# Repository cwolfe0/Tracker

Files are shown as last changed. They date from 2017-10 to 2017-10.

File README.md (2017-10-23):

# SHC HAB Tracker
This is the Eagle schematic and board file for the Space Hardware Club HAB tracker.
It is capable of recording GPS, rotation data, pressure and temperature and sending the information via APRS and recording it to an SD card.

The board uses a:
- GPS
- Magnetometer
- MCU
- 5V Regulator
- 3.3V Regulator
- 2 Surefire C123A Batteries in series (6V, 3000mAh)
- APRS-capable Radio
- 2 Logic Gates (for allowing 5V input to the radio from the MCU)
- Pressure Sensor
- Slider Switch
- PDI Interface

Top Image Top of Board
Bottom Image Bottom of Board
Board Image

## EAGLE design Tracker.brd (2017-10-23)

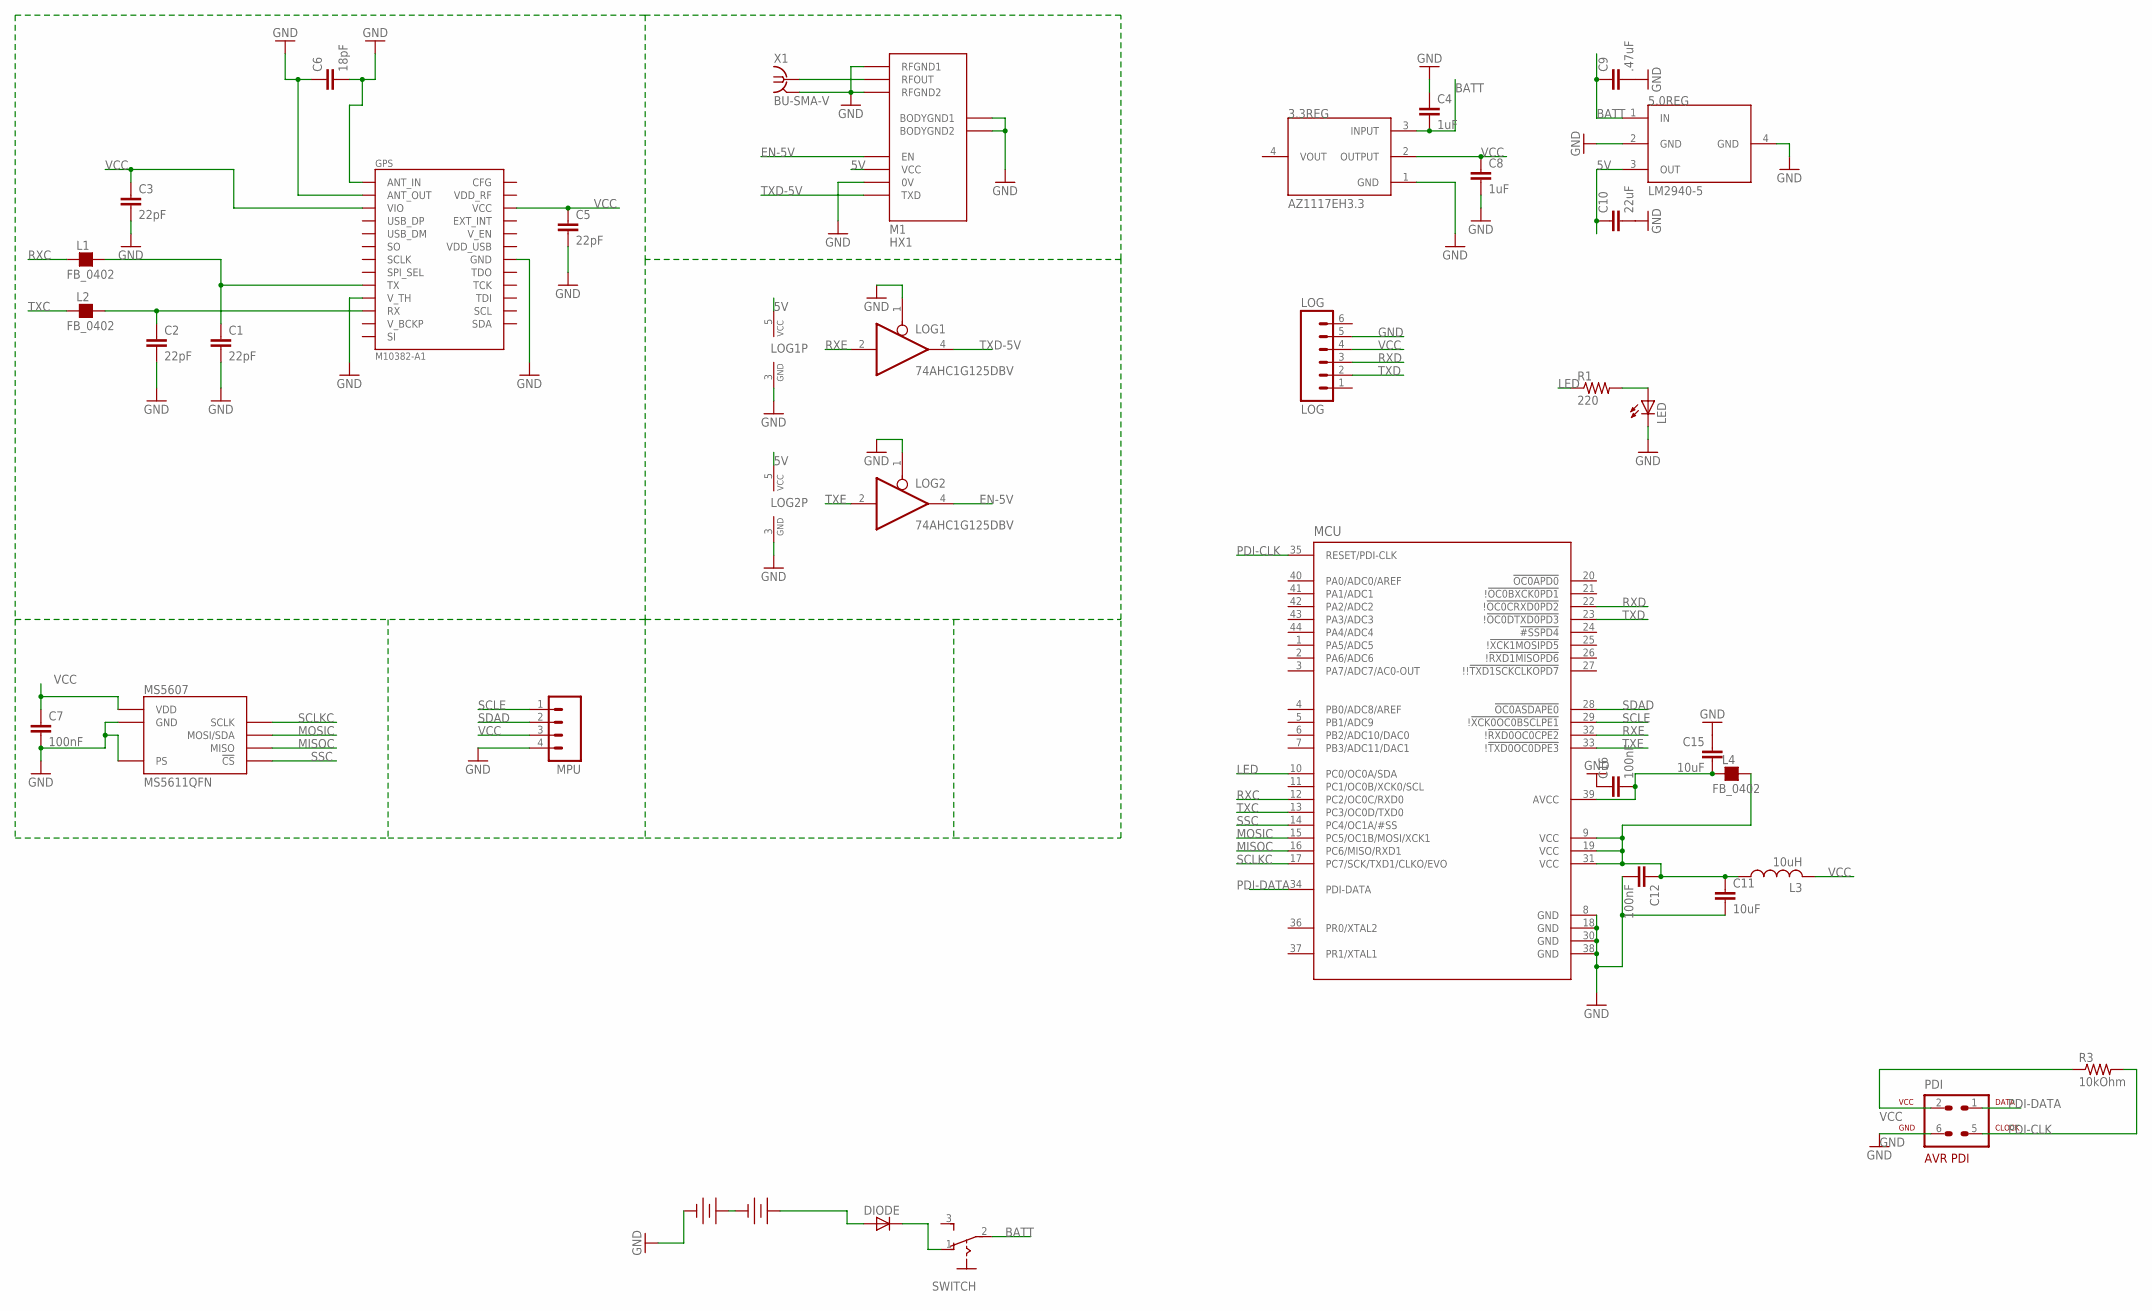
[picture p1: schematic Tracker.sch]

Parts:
3.3REG: AZ1117EH3.3; SOT-223
5.0REG: LM2940-5; SOT-223
BATT1, BATT2: 123_BATTERY_HOLDERCR-123-A; CR-123-A_HOLDER
C1, C2, C3, C5: 22pF; 0805
C4, C8: 1uF; 0603-CAP
C6: 18pF; 0805
C7, C12, C16: 100nF; 0805
C9: .47uF; 0603-CAP
C10: 22uF; 0603-CAP
C11, C15: 10uF; 0805
DIODE: LILYPAD-WEARABLES_LED1206; LILYPAD-WEARABLES_LED-1206
GPS: M10382-A1
L1, L2, L4: FB_0402; L0402
L3: 10uH; L2012C
LED: LEDCHIP-LED0603; CHIP-LED0603
LOG: LOG; SPARKFUN_1X06
LOG1, LOG2: 74AHC1G125DBV; SOT23-5
M1: HX1
MCU: AT-XMEGA-XXA4-AU; QFP80P1200X1200X120-44N
MPU: M04; 04P
MS5607: MS5611QFN; MS5611-01BA01
PDI: AVR-7_AVR-PDIVERT; AVR-7_AVR-ISP-6
R1: 220; R0603
R3: 10kOhm; 0805
SWITCH: M251
X1: BU-SMA-V

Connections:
5V: 5.0REG.3 (OUT), C10.1, LOG1.5 (VCC), LOG2.5 (VCC), M1.VCC
AVCC: C15.2, C16.2, L4.1, MCU.39 (AVCC)
BATT: 3.3REG.3 (INPUT), 5.0REG.1 (IN), C4.2, C9.1, SWITCH.2
EN-5V: LOG2.4 (O), M1.EN
GND: 3.3REG.1 (GND), 5.0REG.2 (GND), 5.0REG.4 (GND), BATT2.-, C1.2, C2.2, C3.2, C4.1, C5.2, C6.1, C6.2, C7.2, C8.2, C9.2, C10.2, C11.2, C12.2, C15.1, C16.1, GPS.1 (ANT_IN), GPS.2 (GND), GPS.3 (ANT_OUT), GPS.4 (GND), GPS.12 (V_TH), GPS.14 (GND), GPS.17 (GND), GPS.21 (GND), GPS.24 (GND), GPS.26 (GND), GPS.28 (GND), GPS.33 (GND), GPS.34 (GND), GPS.35 (GND), GPS.36 (GND), LED.C, LOG.5, LOG1.1 (OE), LOG1.3 (GND), LOG2.1 (OE), LOG2.3 (GND), M1.0V, M1.BODYGND1, M1.BODYGND2, M1.RFGND1, M1.RFGND2, MCU.8 (GND), MCU.18 (GND), MCU.30 (GND), MCU.38 (GND), MPU.4, MS5607.2 (PS), MS5607.3 (GND), PDI.6, X1.2 (GND), X1.3 (GND), X1.4 (GND), X1.5 (GND)
LED: MCU.10 (PC0/OC0A/SDA), R1.1
MISOC: MCU.16 (PC6/MISO/RXD1), MS5607.6 (MISO)
MOSIC: MCU.15 (PC5/OC1B/MOSI/XCK1), MS5607.7 (MOSI/SDA)
unnamed: C1.1, GPS.11 (TX), L1.2
unnamed: C2.1, GPS.13 (RX), L2.2
unnamed: BATT1.-, BATT2.+
unnamed: M1.RFOUT, X1.1
unnamed: BATT1.+, DIODE.A
unnamed: DIODE.C, SWITCH.1 (O)
unnamed: LED.A, R1.2
unnamed: C11.1, C12.1, L3.1, L4.2, MCU.9 (VCC), MCU.19 (VCC), MCU.31 (VCC)
PDI-CLK: MCU.35 (RESET/PDI-CLK), PDI.5, R3.2
PDI-DATA: MCU.34 (PDI-DATA), PDI.1
RXC: L1.1, MCU.12 (PC2/OC0C/RXD0)
RXD: LOG.3, MCU.22 (!!OC0CRXD0PD2)
RXE: LOG1.2 (I), MCU.32 (!!RXD0OC0CPE2)
SCLE: MCU.29 (!!XCK0OC0BSCLPE1), MPU.1
SCLKC: MCU.17 (PC7/SCK/TXD1/CLKO/EVO), MS5607.8 (SCLK)
SDAD: MCU.28 (!OC0ASDAPE0), MPU.2
SSC: MCU.14 (PC4/OC1A/#SS), MS5607.4 (!CS!), MS5607.5 (!CS!)
TXC: L2.1, MCU.13 (PC3/OC0D/TXD0)
TXD: LOG.2, MCU.23 (!!OC0DTXD0PD3)
TXD-5V: LOG1.4 (O), M1.TXD
TXE: LOG2.2 (I), MCU.33 (!!TXD0OC0DPE3)
VCC: 3.3REG.2 (OUTPUT), C3.1, C5.1, C7.1, C8.1, GPS.5 (VIO), GPS.27 (VCC), L3.2, LOG.4, MPU.3, MS5607.1 (VDD), PDI.2, R3.1

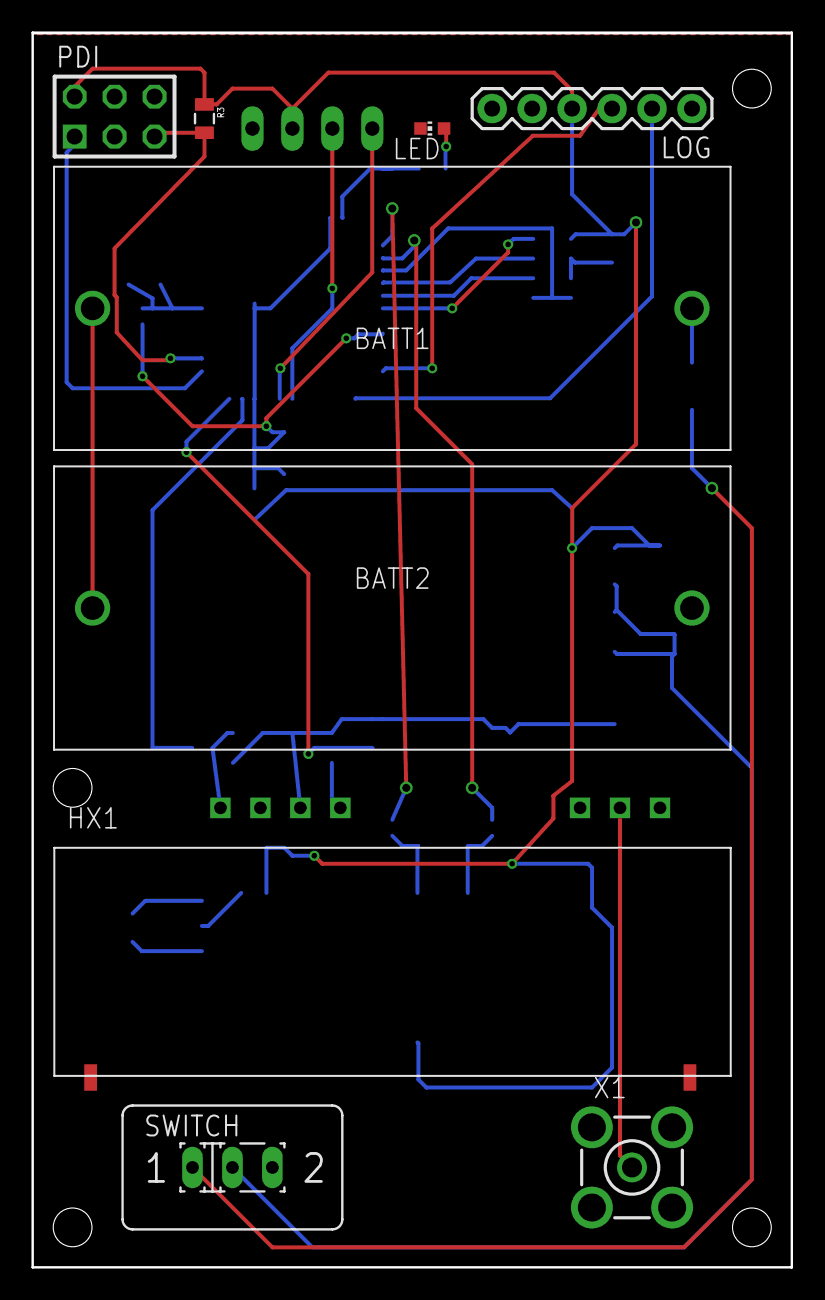
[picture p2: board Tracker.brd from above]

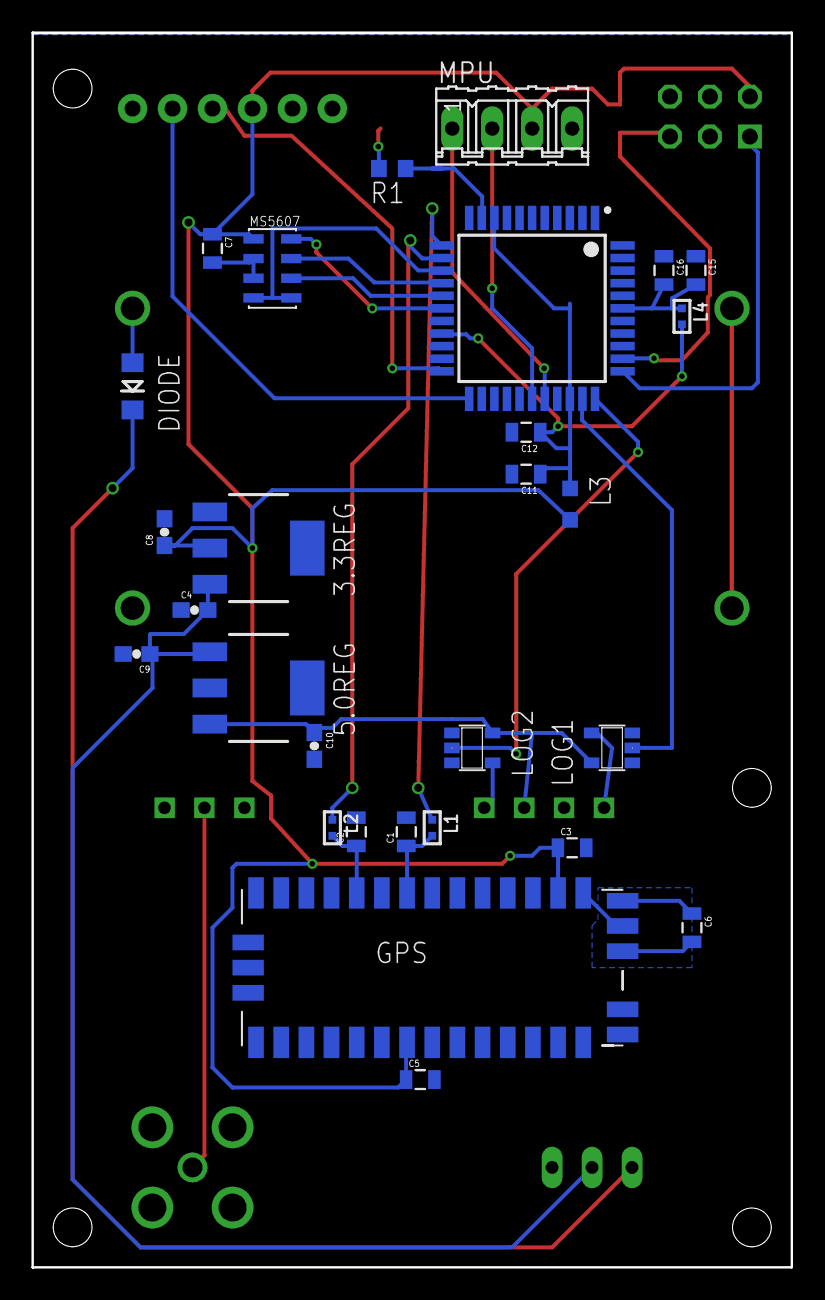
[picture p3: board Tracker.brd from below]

Board: 2 copper layers, 48.3 x 78.5 mm, 37 parts (28 on the bottom side), 30 nets.

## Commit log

2017-10-23 rev 1
    [Tracker.brd, Tracker.sch, TrackerNoGPlane.brd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]
2017-10-23 rev2
    Removed .x#h files, removed teaching examples, shrunk footprint, made project library
    [Tracker.brd, Tracker.sch, TrackerNoGPlane.brd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]
2017-10-23 Update Readme, add GERBER
    Change Readme to be more representative of the tracker instead of Physoon, add SeedFusion CAM files, remove errant EAGLE files
2017-10-23 DRILL KILL
    added drills, sorry for bad commit summary
    [Tracker.brd]

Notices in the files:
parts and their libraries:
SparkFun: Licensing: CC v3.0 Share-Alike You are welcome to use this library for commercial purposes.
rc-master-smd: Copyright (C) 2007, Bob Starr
